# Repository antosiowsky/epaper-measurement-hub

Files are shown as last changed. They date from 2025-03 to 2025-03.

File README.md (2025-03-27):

# Epaper-EnvMonitor

A low-power environmental monitoring hub with an e-paper display, based on the M5StampS3 processor. It features a BME688 sensor for temperature, humidity, and air quality measurement, along with data storage and wireless communication.

## Features
- **Real-time environmental monitoring** (temperature, humidity, air quality)
- **E-paper display** for low-power data visualization
- **Data storage** for historical measurements
- **Wireless communication** (Wi-Fi/Bluetooth) for remote access
- **Energy-efficient design** suitable for battery-powered operation

## Hardware Components
- **M5StampS3** – ESP32-S3 based microcontroller
- **BME688** – Temperature, humidity, and gas sensor
- **E-paper display** – Low-power screen for data visualization
- **Memory module** – For data logging and storage

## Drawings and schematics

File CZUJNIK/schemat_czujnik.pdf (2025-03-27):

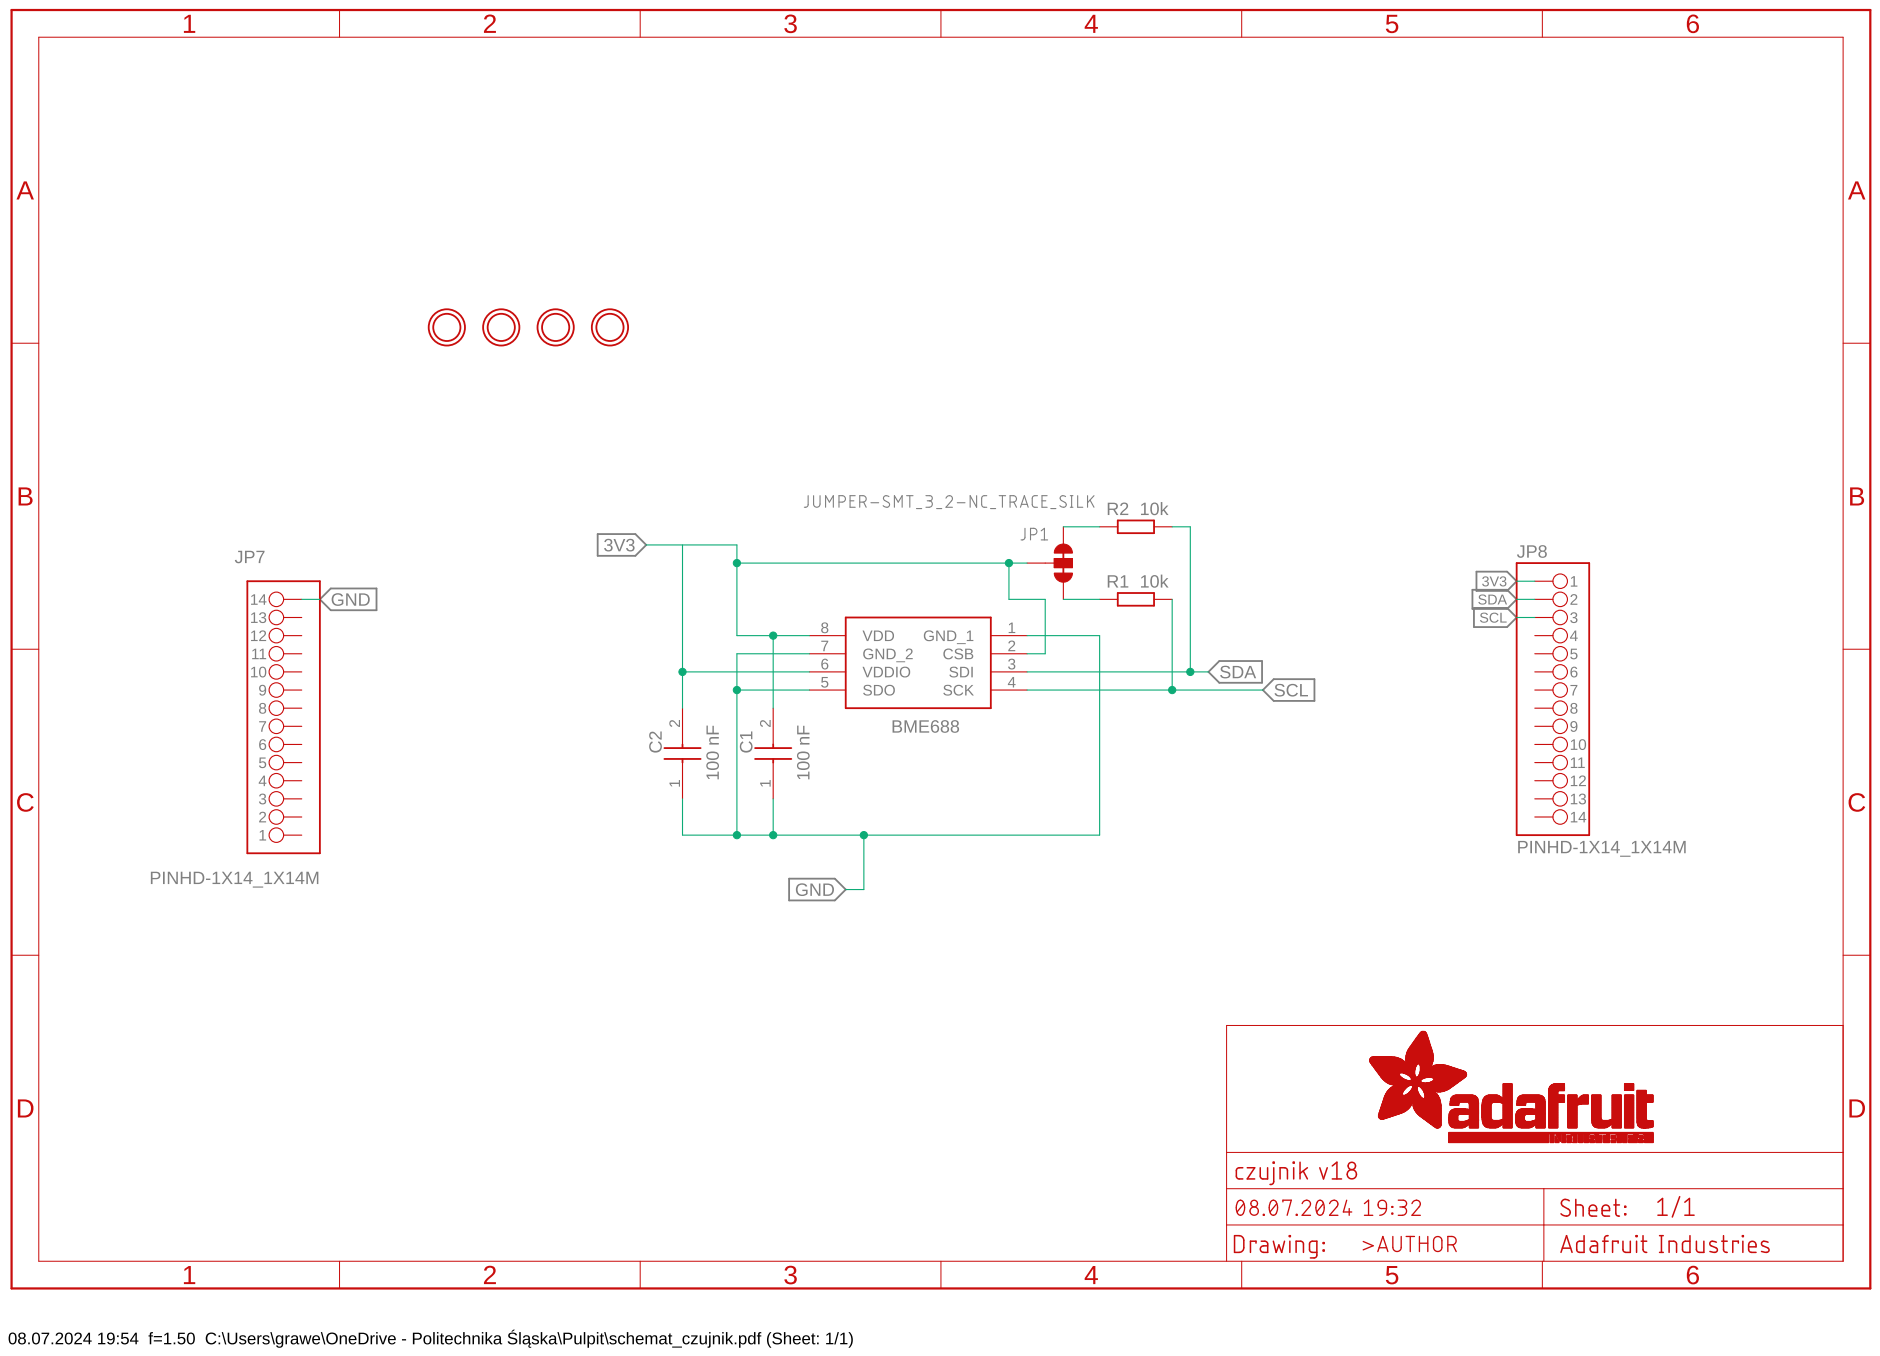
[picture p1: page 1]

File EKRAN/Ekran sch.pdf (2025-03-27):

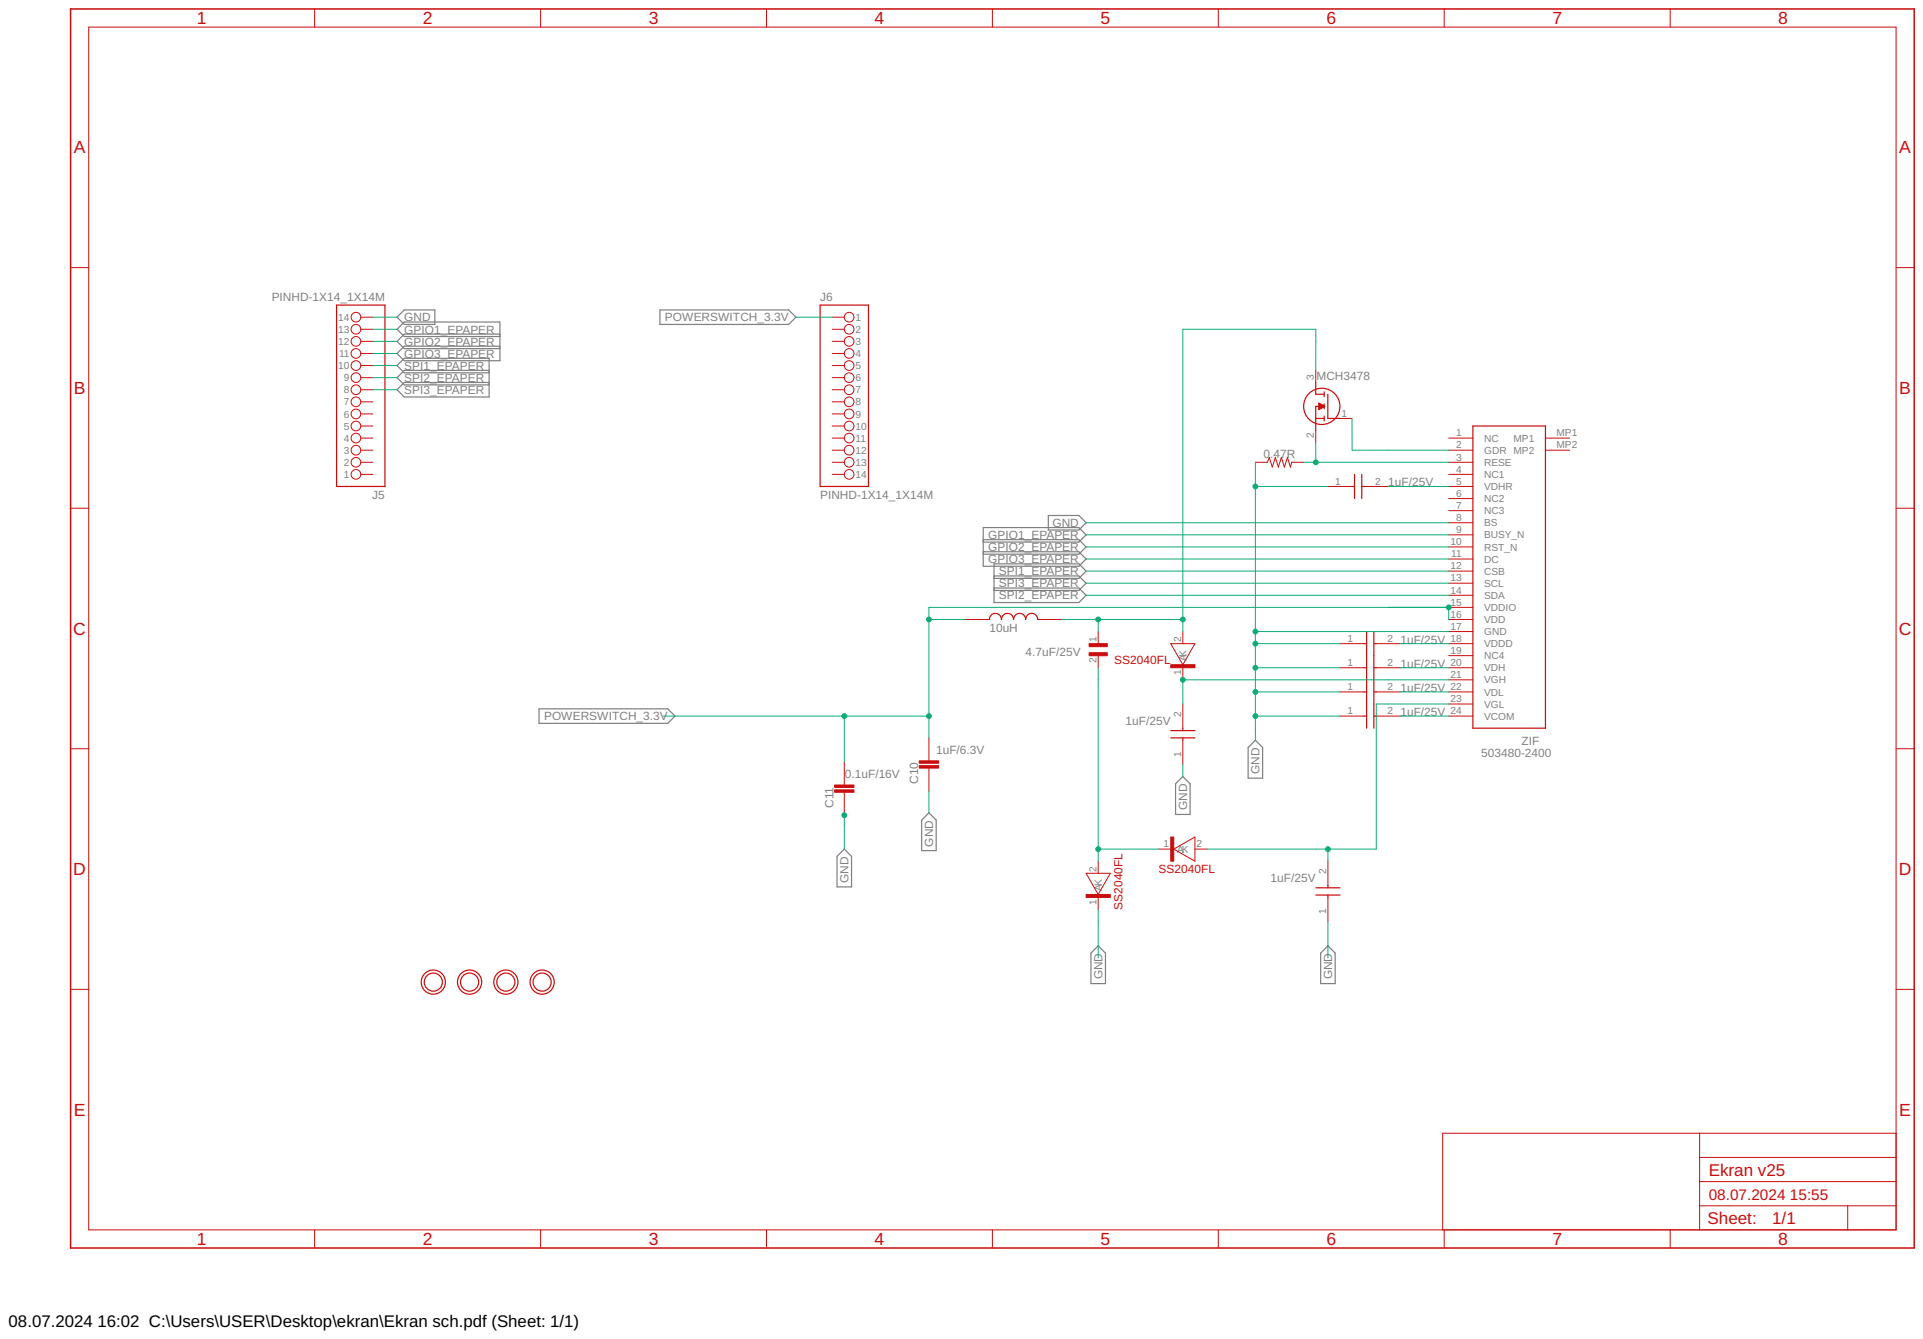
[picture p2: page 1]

08.07.2024 16:02 C:\Users\USER\Desktop\ekran\Ekran sch.pdf (Sheet: 1/1)

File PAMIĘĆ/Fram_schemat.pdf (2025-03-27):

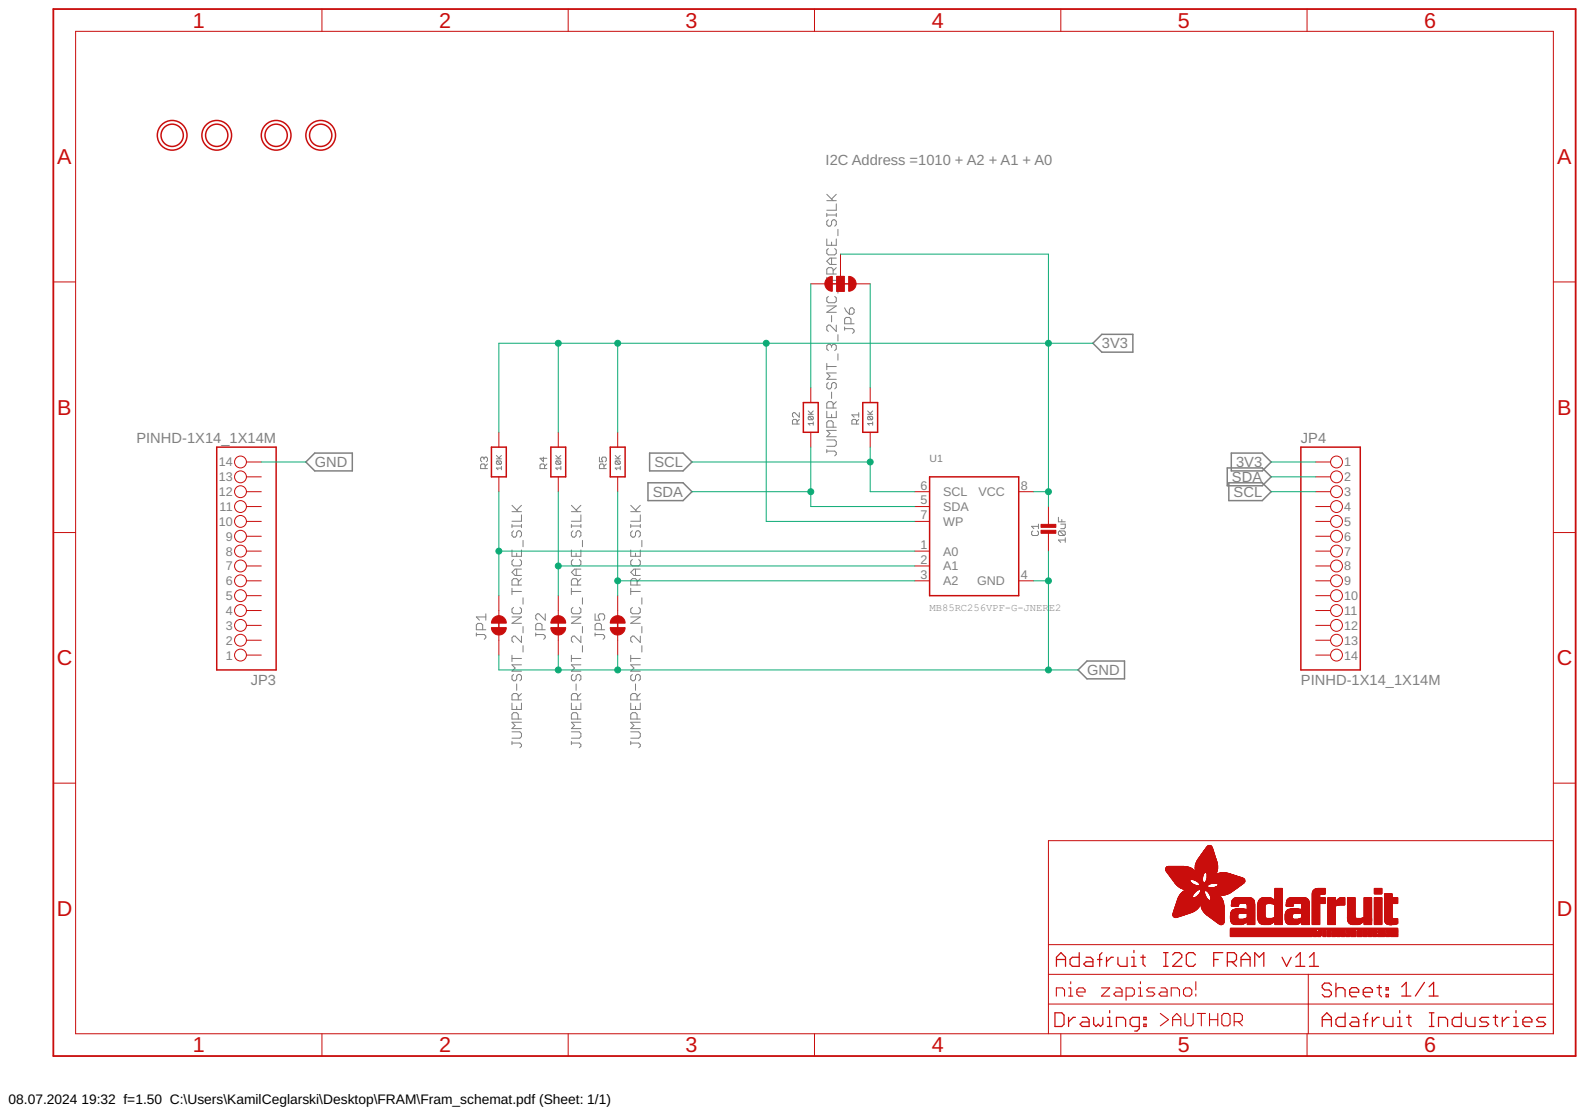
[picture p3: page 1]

08.07.2024 19:32 f=1.50 C:\Users\KamilCeglarski\Desktop\FRAM\Fram_schemat.pdf (Sheet: 1/1)

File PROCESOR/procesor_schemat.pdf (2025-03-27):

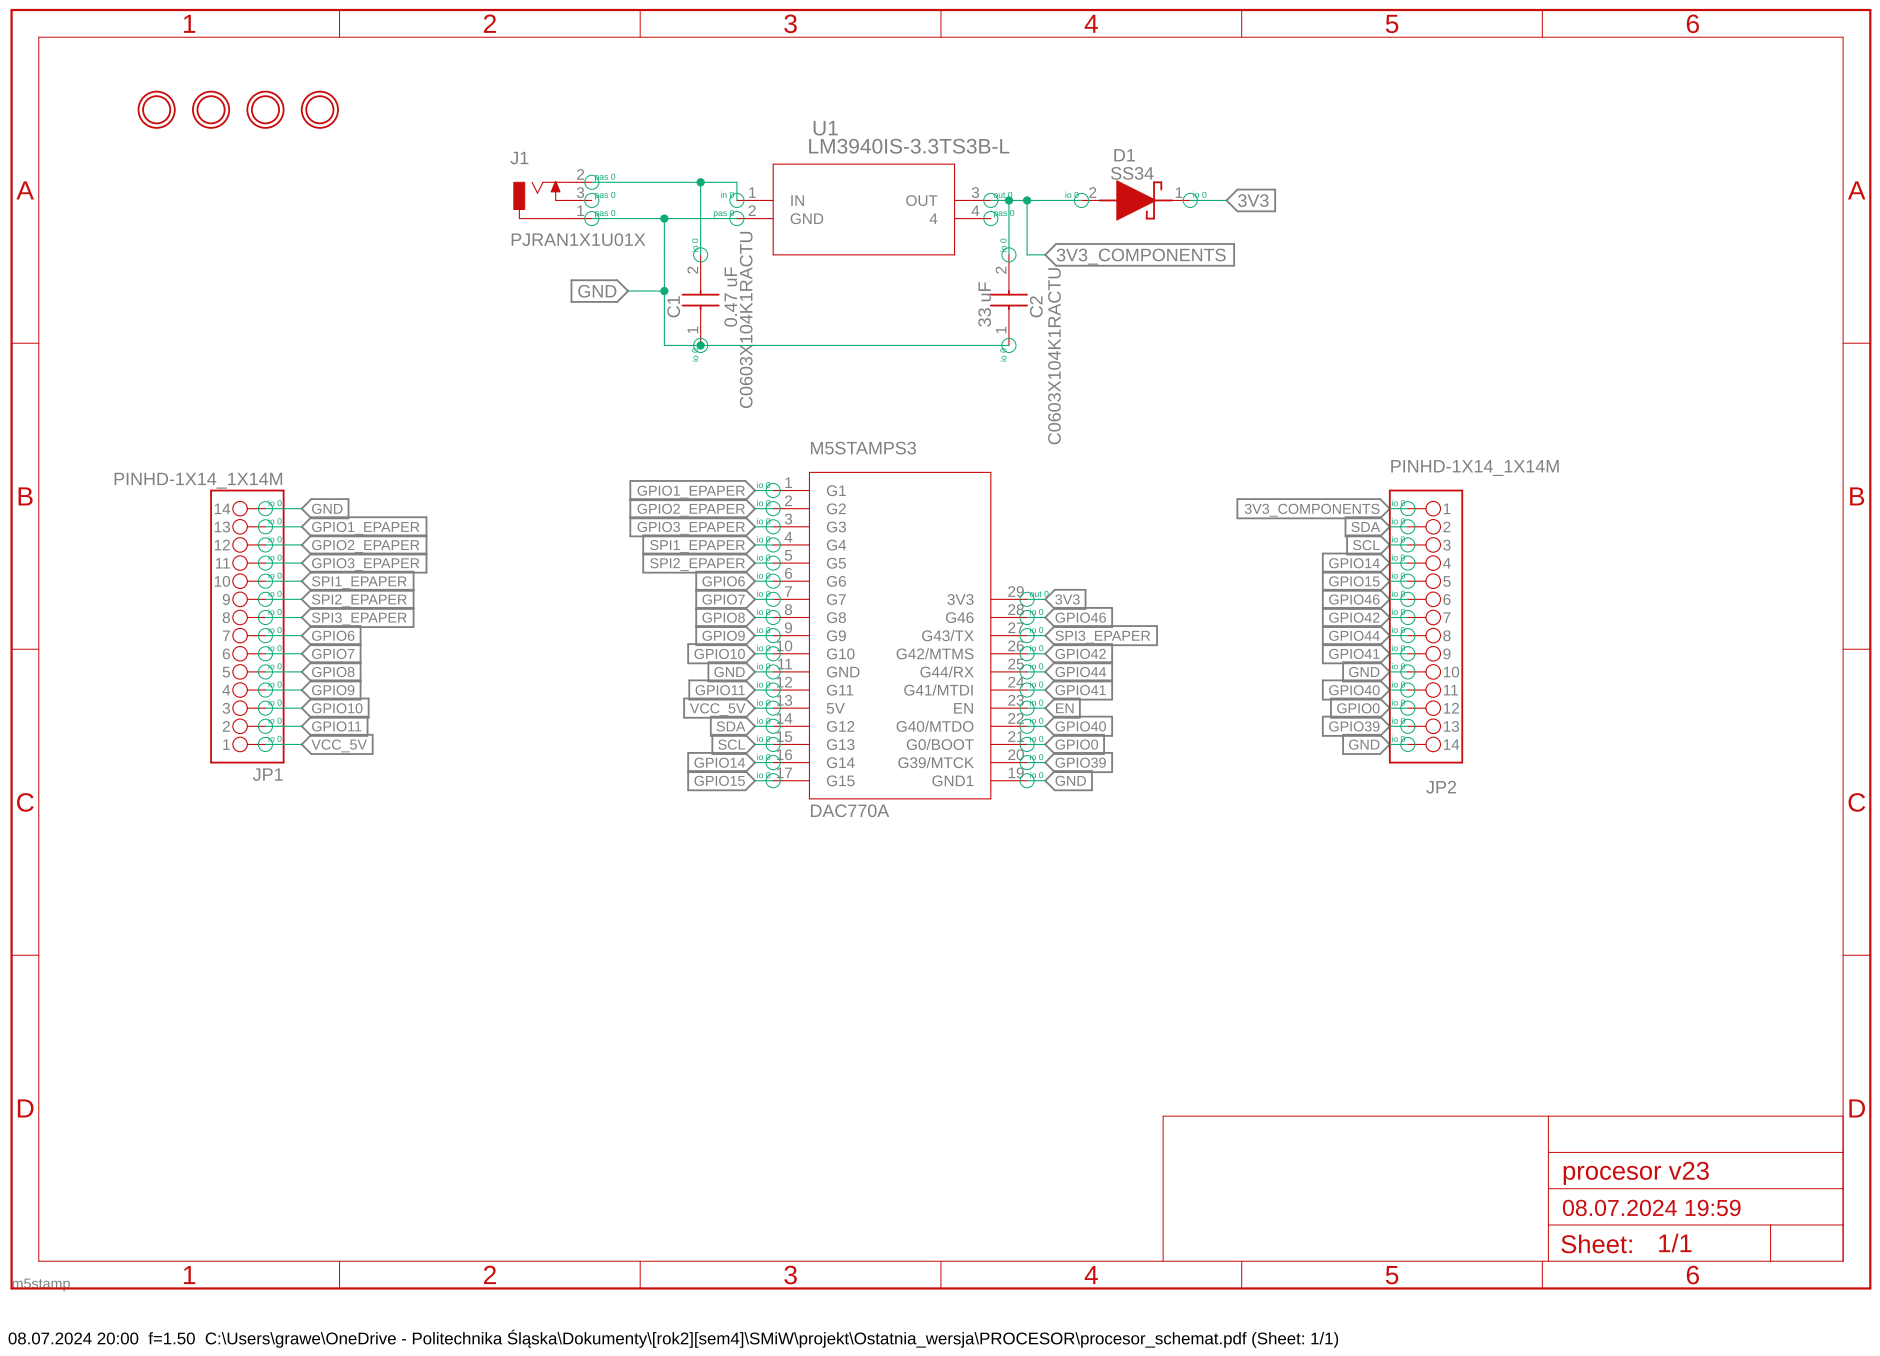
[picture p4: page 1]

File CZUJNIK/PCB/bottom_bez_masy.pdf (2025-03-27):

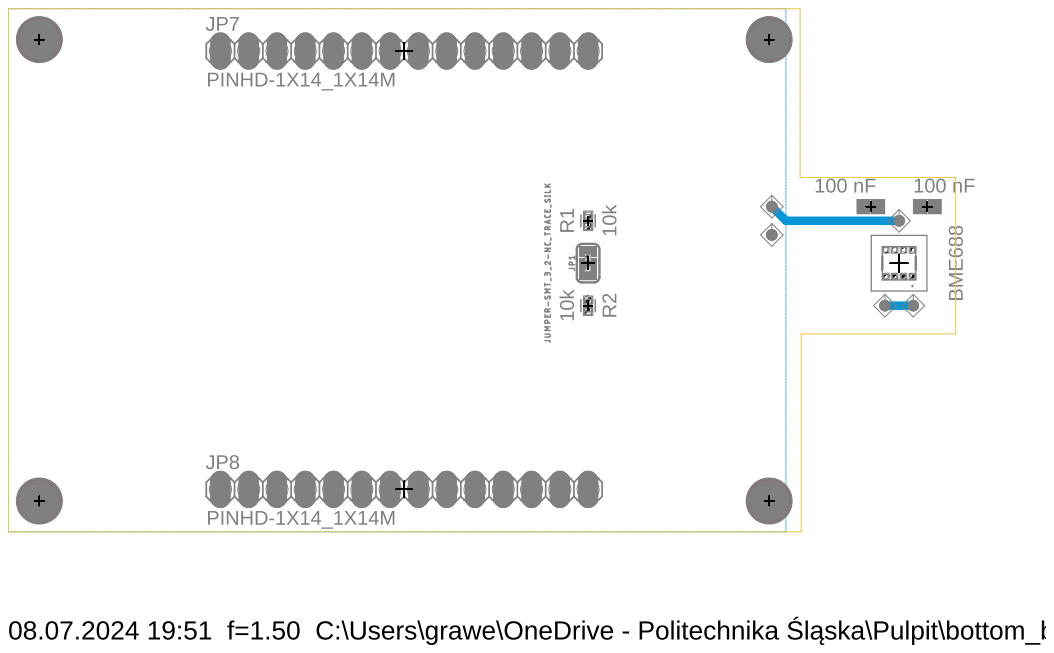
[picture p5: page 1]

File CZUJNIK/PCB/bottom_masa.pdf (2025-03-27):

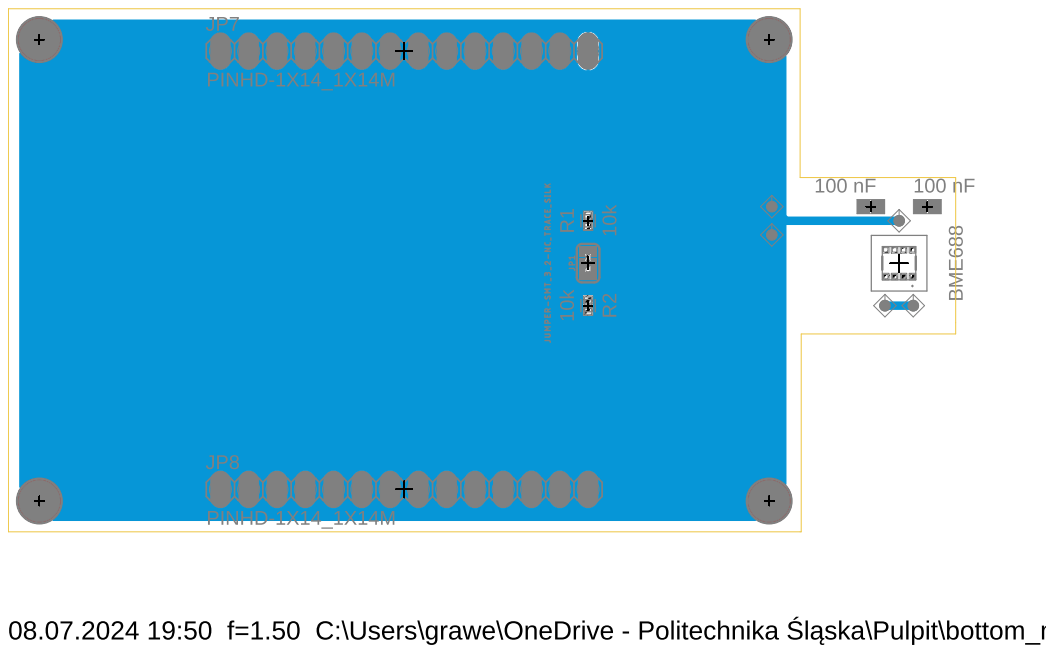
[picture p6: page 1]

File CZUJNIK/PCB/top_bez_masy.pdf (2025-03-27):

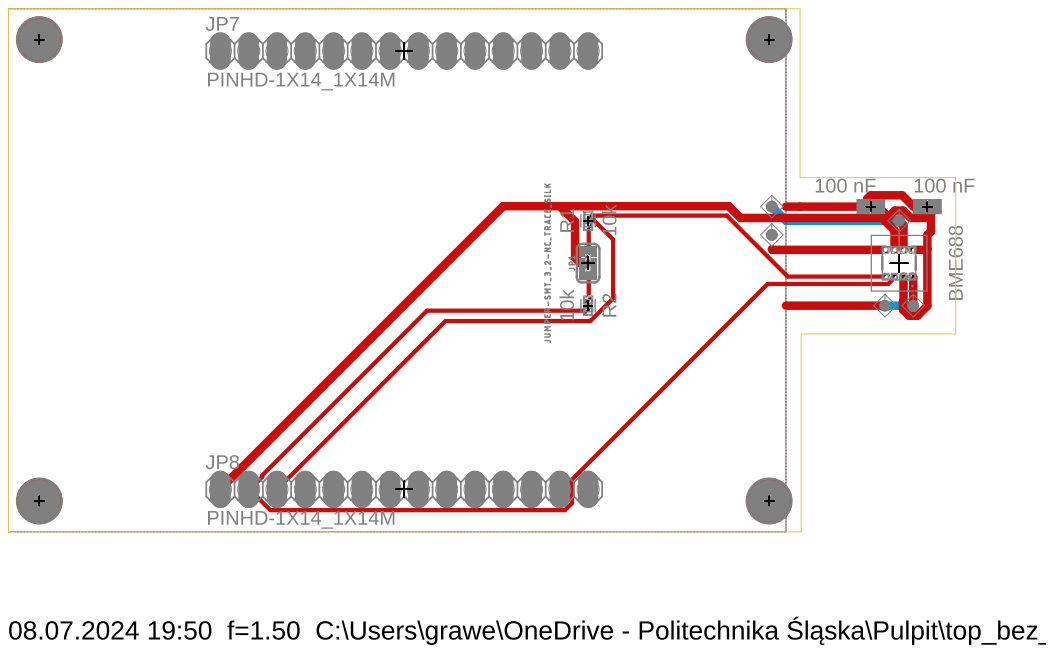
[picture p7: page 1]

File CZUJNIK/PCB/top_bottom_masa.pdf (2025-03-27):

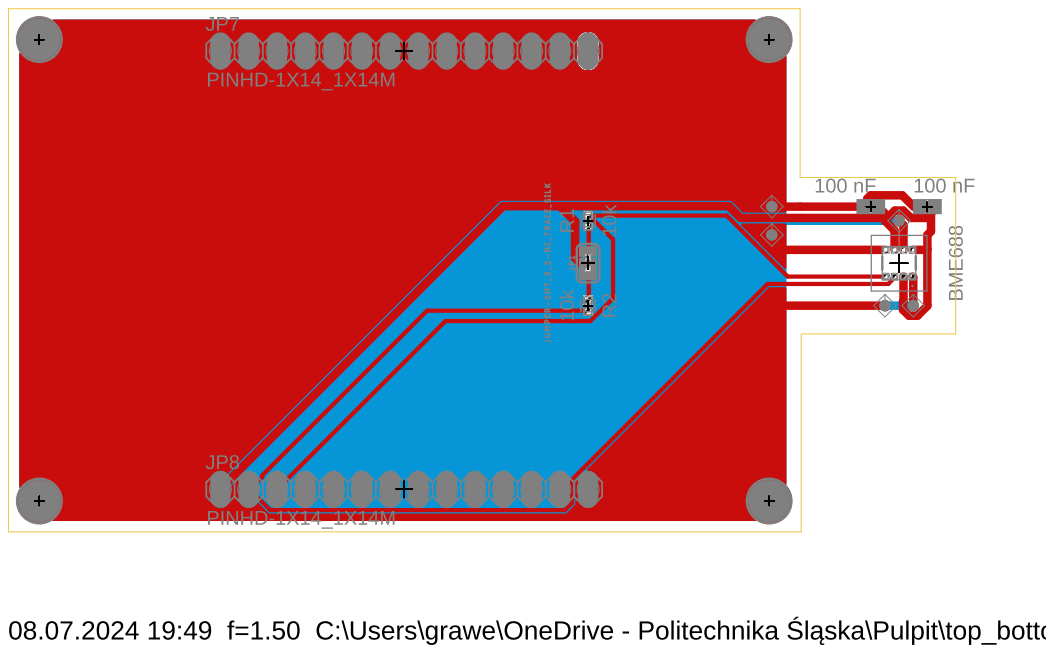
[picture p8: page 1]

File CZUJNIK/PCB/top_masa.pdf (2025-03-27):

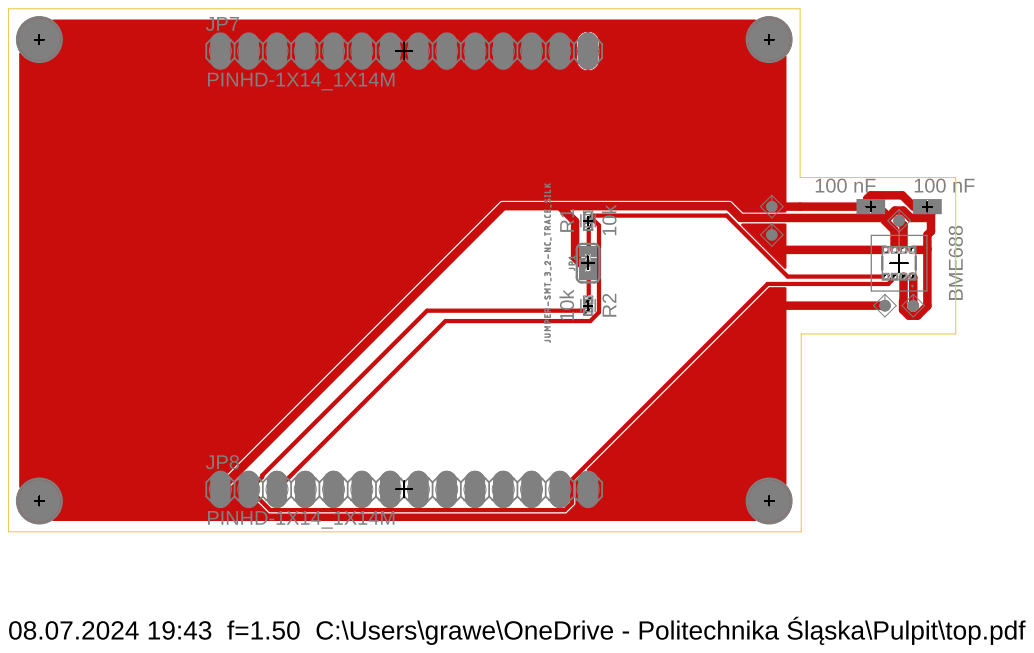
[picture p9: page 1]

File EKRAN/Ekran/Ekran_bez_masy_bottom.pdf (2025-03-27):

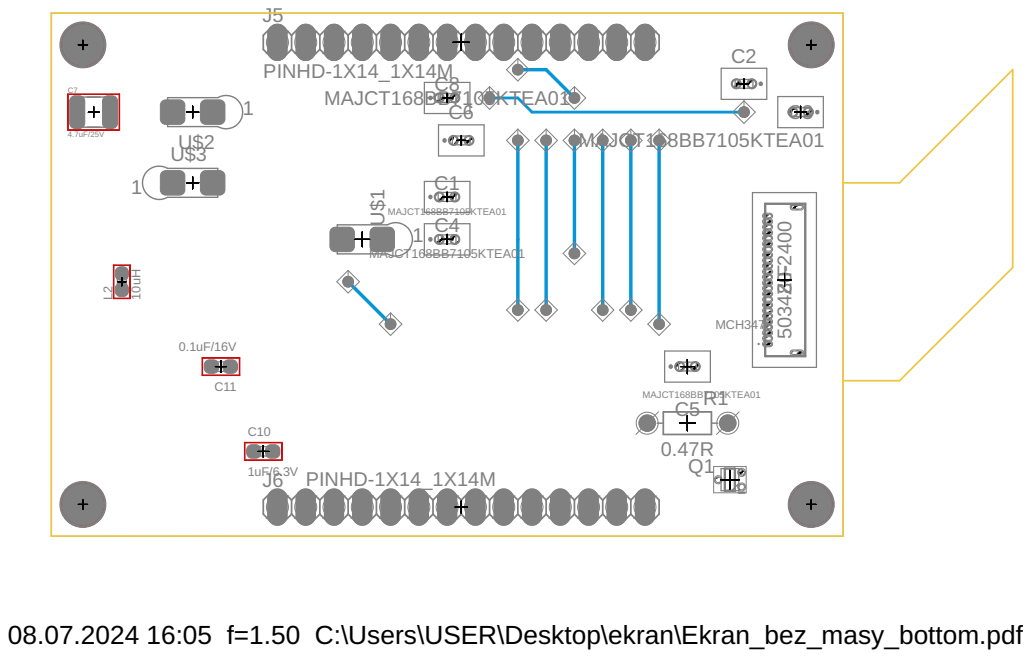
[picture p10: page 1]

08.07.2024 16:05 f=1.50 C:\Users\USER\Desktop\ekran\Ekran_bez_masy_bottom.pdf

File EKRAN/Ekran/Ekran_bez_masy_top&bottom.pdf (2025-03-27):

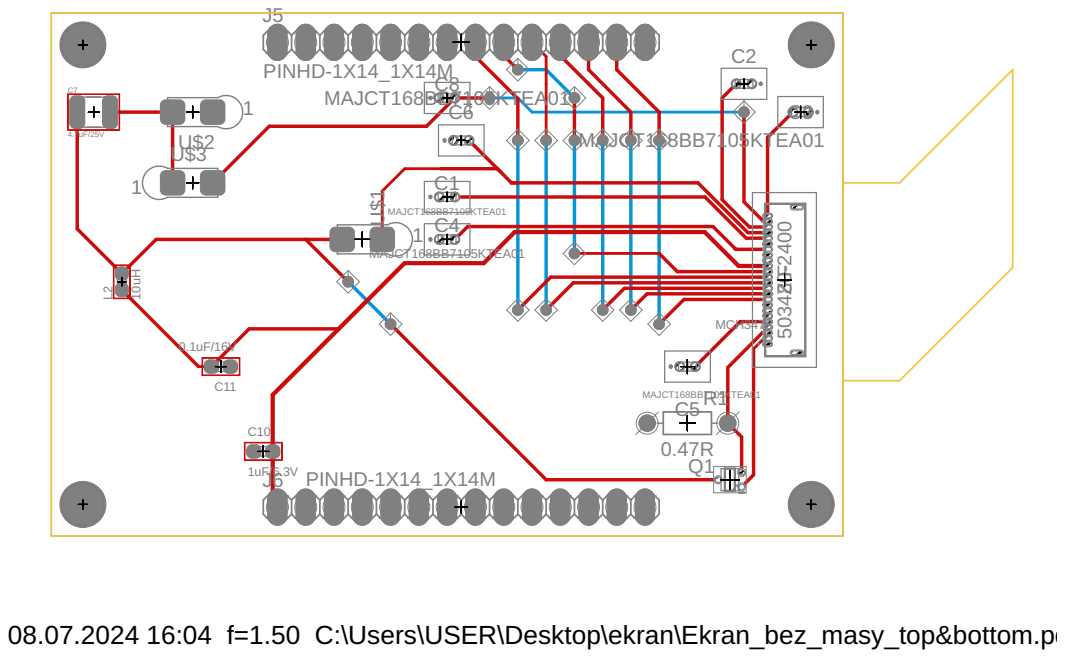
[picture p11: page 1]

08.07.2024 16:04 f=1.50 C:\Users\USER\Desktop\ekran\Ekran_bez_masy_top&bottom.pdf

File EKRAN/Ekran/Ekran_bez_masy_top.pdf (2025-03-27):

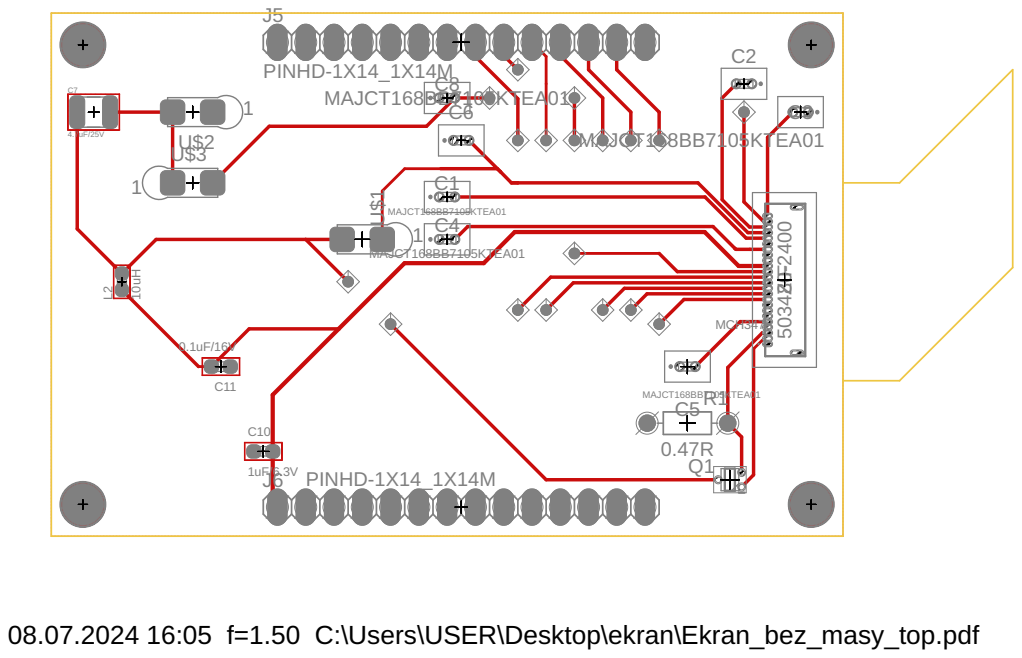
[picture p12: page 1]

08.07.2024 16:05 f=1.50 C:\Users\USER\Desktop\ekran\Ekran_bez_masy_top.pdf

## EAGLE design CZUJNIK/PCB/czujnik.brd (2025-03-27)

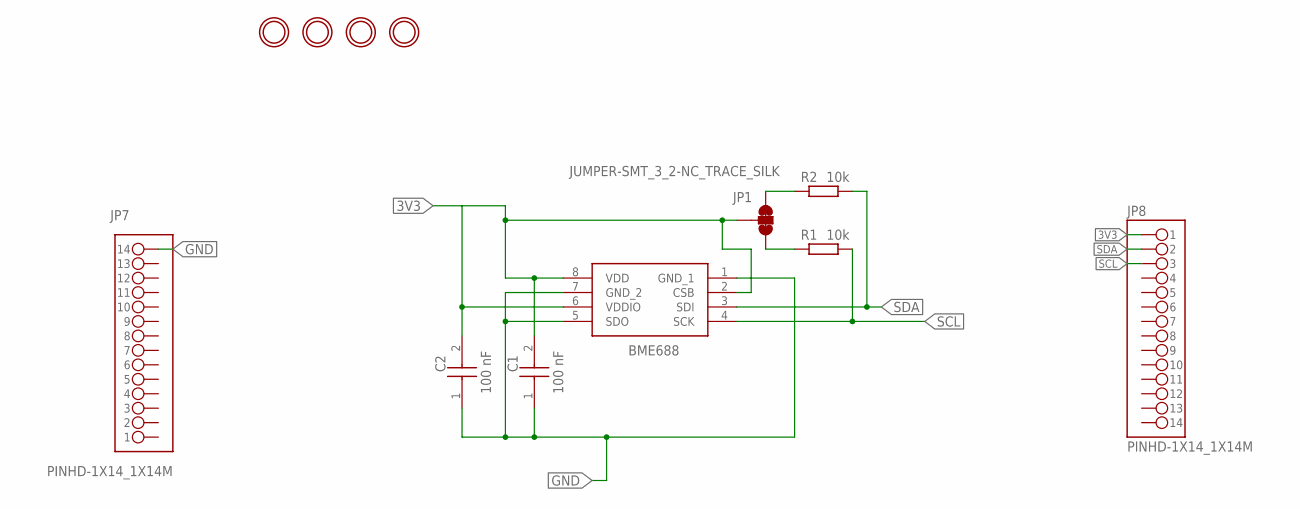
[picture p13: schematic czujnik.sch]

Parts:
BME688: BME688
C1, C2: C0603X104K1RACTU; CAPC1608X100N
JP1: JUMPER-SMT_3_2-NC_TRACE_SILK; SMT-JUMPER_3_2-NC_TRACE_SILK
JP7, JP8: PINHD-1X14_1X14M; 1X14
R1, R2: 10k; RESC1005X40
U$2, U$3, U$4, U$6: MOUNTINGHOLE2.5; MOUNTINGHOLE_2.5_PLATED

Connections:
3V3: BME688.2 (CSB), BME688.6 (VDDIO), BME688.8 (VDD), C1.2, C2.2, JP1.2, JP8.1
GND: BME688.1 (GND_1), BME688.5 (SDO), BME688.7 (GND_2), C1.1, C2.1, JP7.14
unnamed: JP1.1, R2.1
unnamed: JP1.3, R1.1
SCL: BME688.4 (SCK), JP8.3, R1.2
SDA: BME688.3 (SDI), JP8.2, R2.2

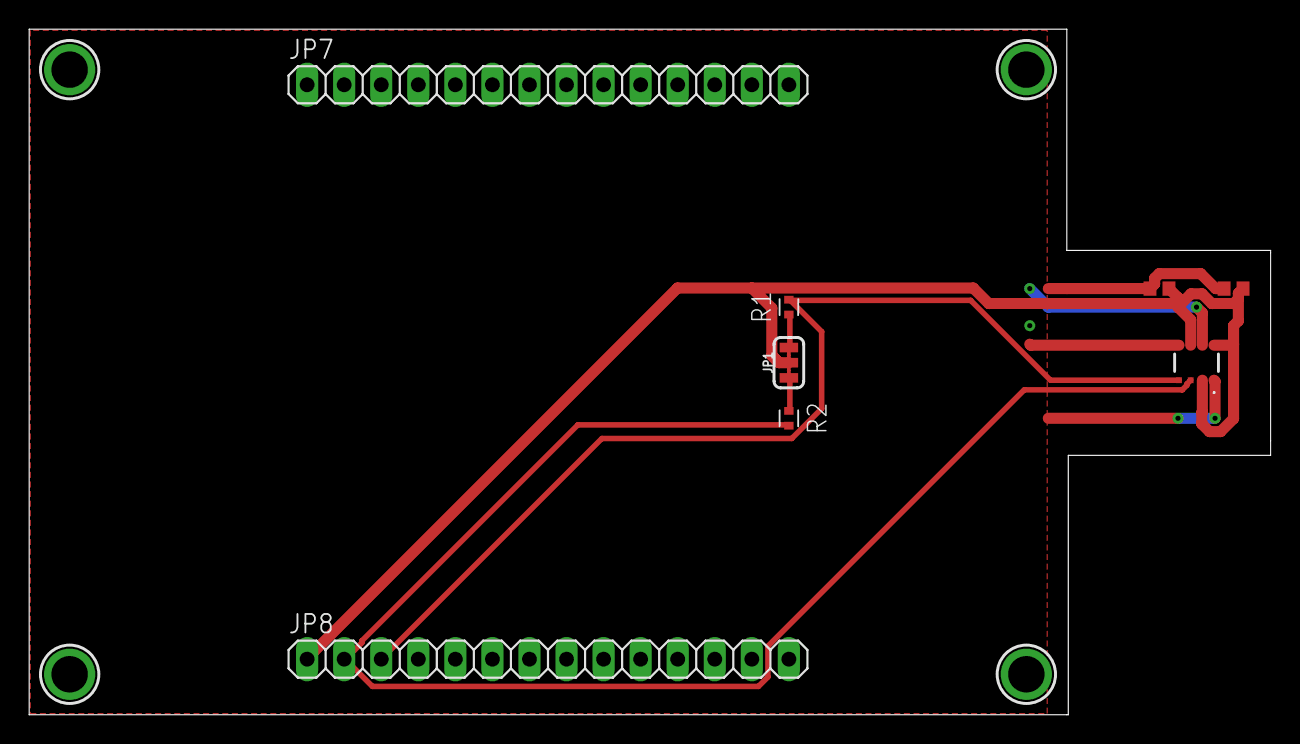
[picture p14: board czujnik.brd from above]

Board: 2 copper layers, 85.1 x 47.0 mm, 12 parts (0 on the bottom side), 6 nets.

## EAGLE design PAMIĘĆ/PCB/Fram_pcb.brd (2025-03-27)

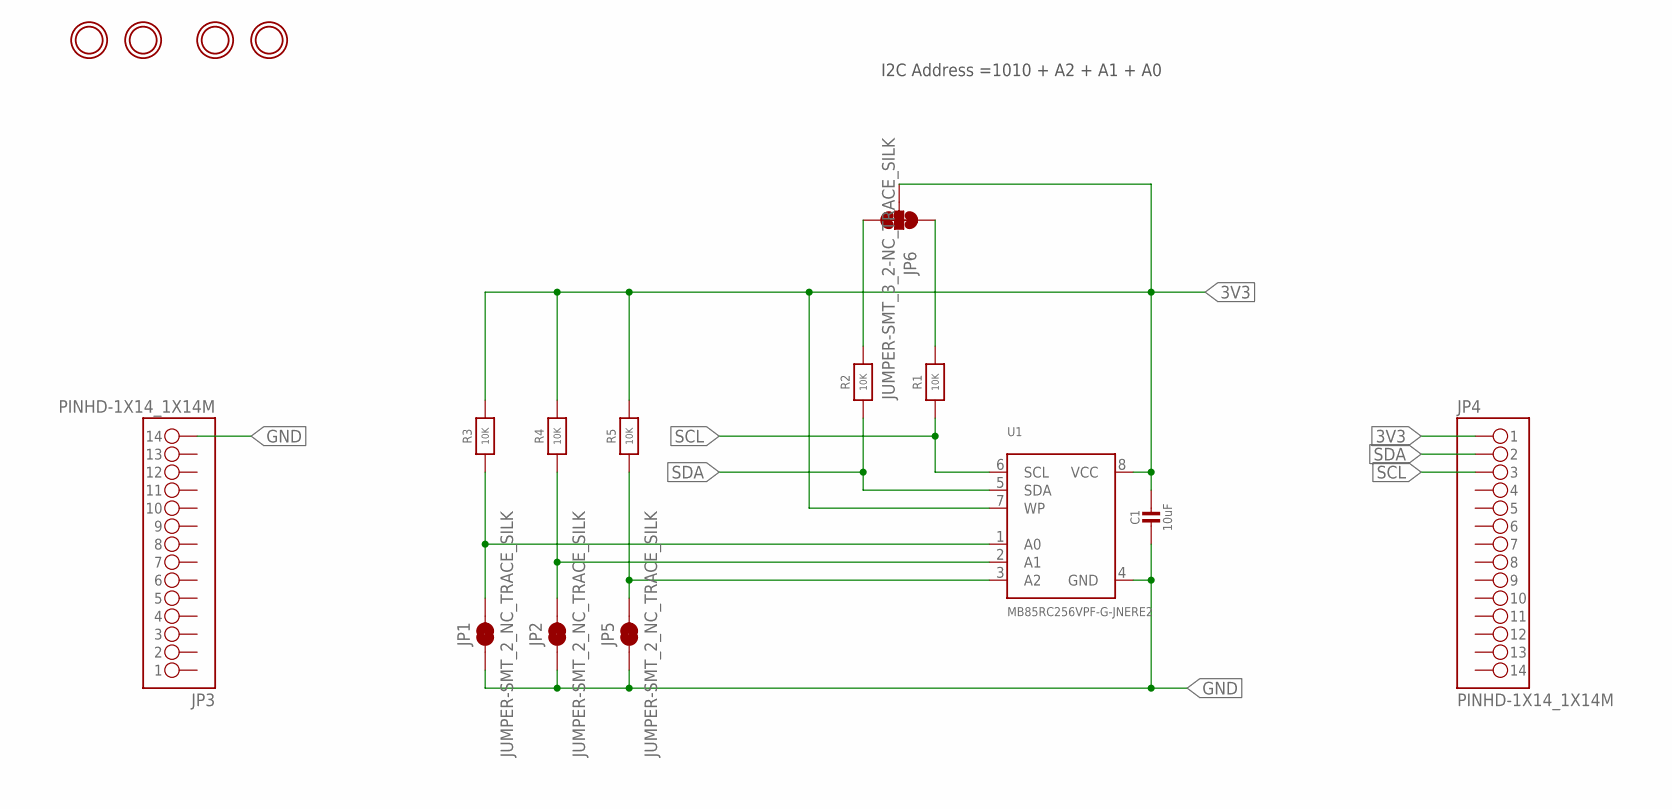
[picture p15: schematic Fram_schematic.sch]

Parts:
C1: 10uF; _0805MP
JP1, JP2, JP5: JUMPER-SMT_2_NC_TRACE_SILK; SMT-JUMPER_2_NC_TRACE_SILK
JP3, JP4: PINHD-1X14_1X14M; 1X14
JP6: JUMPER-SMT_3_2-NC_TRACE_SILK; SMT-JUMPER_3_2-NC_TRACE_SILK
R1, R2, R3, R4, R5: 10K; _0805MP
U1: MB85RC256VPF-G-JNERE2; SOIC8_208MIL
U$2, U$3, U$5, U$6: MOUNTINGHOLE2.5; MOUNTINGHOLE_2.5_PLATED

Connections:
3V3: C1.1, JP4.1, JP6.2, R3.2, R4.2, R5.2, U1.7 (WP), U1.8 (VCC)
GND: C1.2, JP1.1, JP2.1, JP3.14, JP5.1, U1.4 (GND)
SCL: JP4.3, JP6.1, R1.1, R1.2, U1.6 (SCL)
SDA: JP4.2, JP6.3, R2.1, R2.2, U1.5 (SDA)
SDA1: JP1.2, R3.1, U1.1 (A0)
SDA2: JP2.2, R4.1, U1.2 (A1)
SDA3: JP5.2, R5.1, U1.3 (A2)

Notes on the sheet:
I2C Address =1010 + A2 + A1 + A0

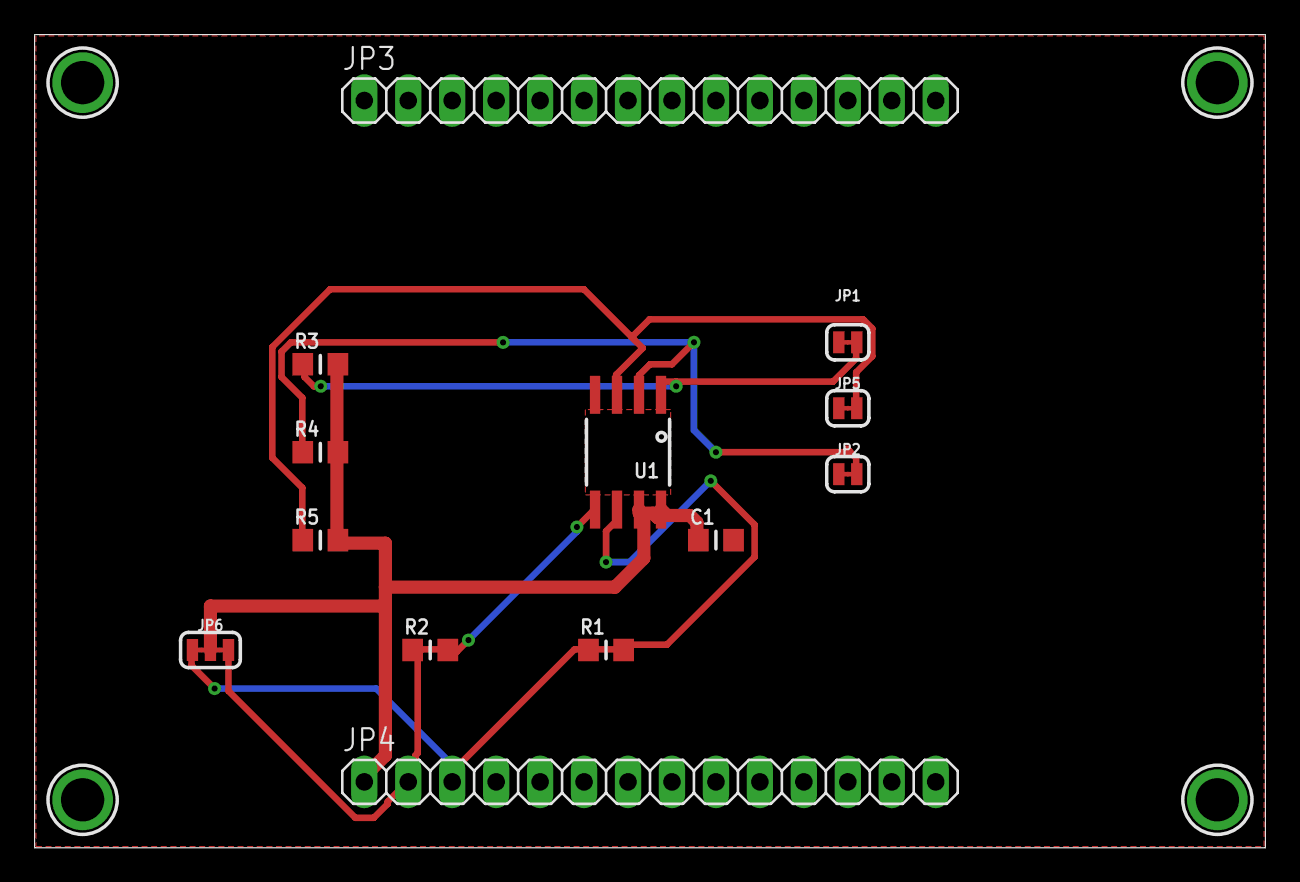
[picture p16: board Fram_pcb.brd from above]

Board: 2 copper layers, 71.1 x 47.0 mm, 17 parts (0 on the bottom side), 7 nets.

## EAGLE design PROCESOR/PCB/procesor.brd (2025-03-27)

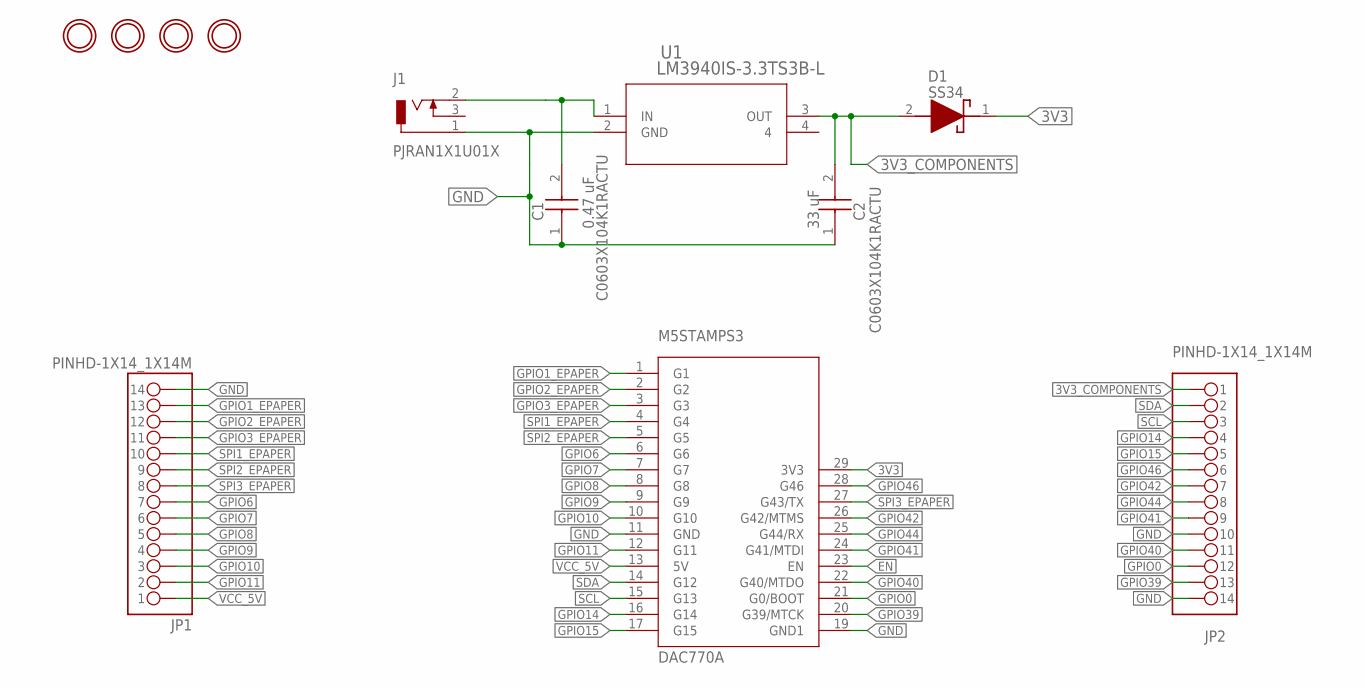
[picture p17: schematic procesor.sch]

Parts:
C1, C2: C0603X104K1RACTU; CAPC1608X100N
D1: SS34; DIOM8059X256N
J1: PJRAN1X1U01X
JP1, JP2: PINHD-1X14_1X14M; 1X14
M5STAMPS3: DAC770A; QFN127P2400X1800X470-36N
U1: LM3940IS-3.3TS3B-L; TS3B-L
U$1, U$3, U$5, U$6: MOUNTINGHOLE2.5; MOUNTINGHOLE_2.5_PLATED

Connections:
3V3: D1.1 (K), M5STAMPS3.29 (3V3)
3V3_COMPONENTS: C2.2, D1.2 (A), JP2.1, U1.3 (OUT)
EN: M5STAMPS3.23 (EN)
GND: C1.1, C2.1, J1.1, JP1.14, JP2.10, JP2.14, M5STAMPS3.11 (GND), M5STAMPS3.19 (GND1), U1.2 (GND)
GPIO0: JP2.12, M5STAMPS3.21 (G0/BOOT)
GPIO1_EPAPER: JP1.13, M5STAMPS3.1 (G1)
GPIO2_EPAPER: JP1.12, M5STAMPS3.2 (G2)
GPIO3_EPAPER: JP1.11, M5STAMPS3.3 (G3)
GPIO6: JP1.7, M5STAMPS3.6 (G6)
GPIO7: JP1.6, M5STAMPS3.7 (G7)
GPIO8: JP1.5, M5STAMPS3.8 (G8)
GPIO9: JP1.4, M5STAMPS3.9 (G9)
GPIO10: JP1.3, M5STAMPS3.10 (G10)
GPIO11: JP1.2, M5STAMPS3.12 (G11)
GPIO14: JP2.4, M5STAMPS3.16 (G14)
GPIO15: JP2.5, M5STAMPS3.17 (G15)
GPIO39: JP2.13, M5STAMPS3.20 (G39/MTCK)
GPIO40: JP2.11, M5STAMPS3.22 (G40/MTDO)
GPIO41: JP2.9, M5STAMPS3.24 (G41/MTDI)
GPIO42: JP2.7, M5STAMPS3.26 (G42/MTMS)
GPIO44: JP2.8, M5STAMPS3.25 (G44/RX)
GPIO46: JP2.6, M5STAMPS3.28 (G46)
unnamed: C1.2, J1.2, U1.1 (IN)
SCL: JP2.3, M5STAMPS3.15 (G13)
SDA: JP2.2, M5STAMPS3.14 (G12)
SPI1_EPAPER: JP1.10, M5STAMPS3.4 (G4)
SPI2_EPAPER: JP1.9, M5STAMPS3.5 (G5)
SPI3_EPAPER: JP1.8, M5STAMPS3.27 (G43/TX)
VCC_5V: JP1.1, M5STAMPS3.13 (5V)

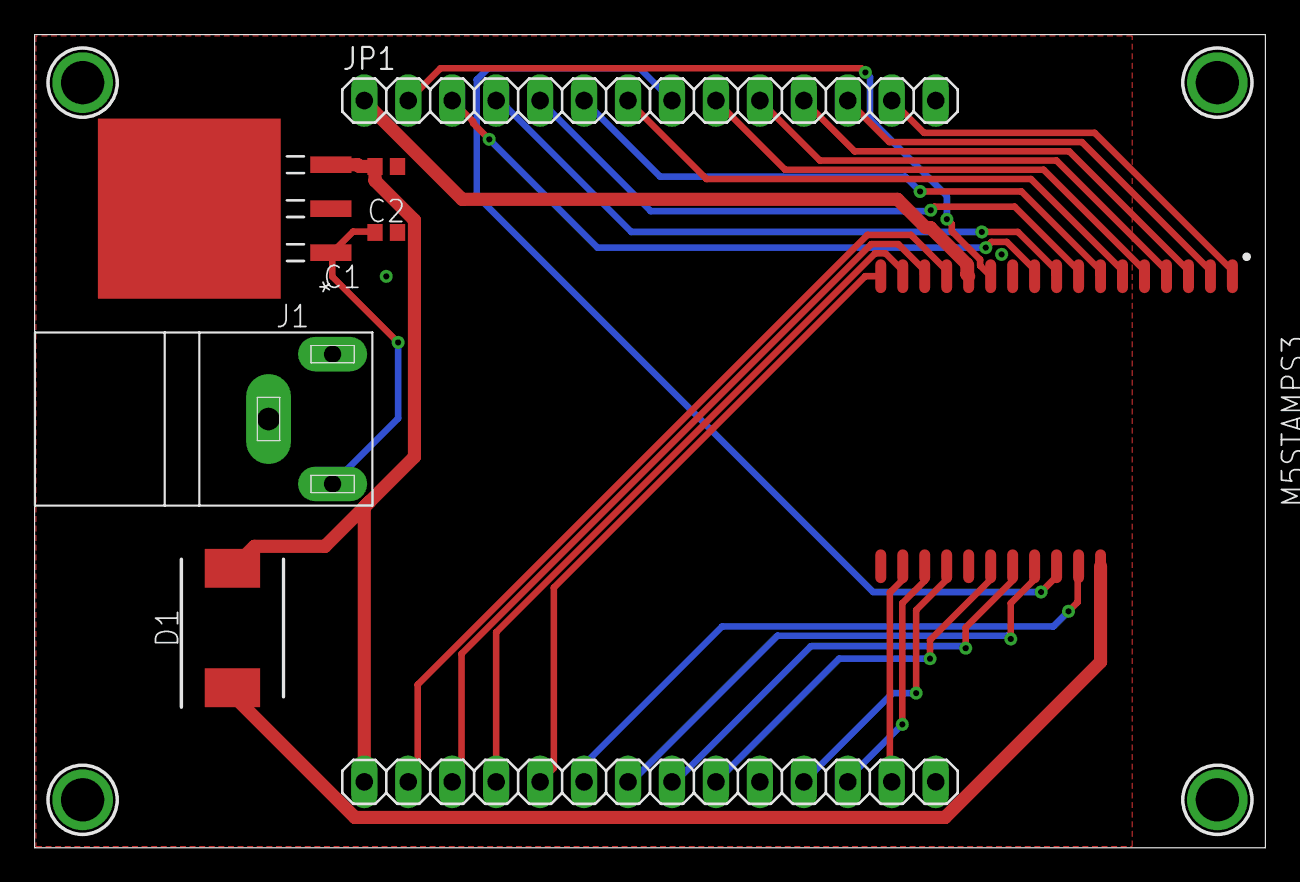
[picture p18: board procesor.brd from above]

Board: 2 copper layers, 71.1 x 47.0 mm, 12 parts (0 on the bottom side), 28 nets.

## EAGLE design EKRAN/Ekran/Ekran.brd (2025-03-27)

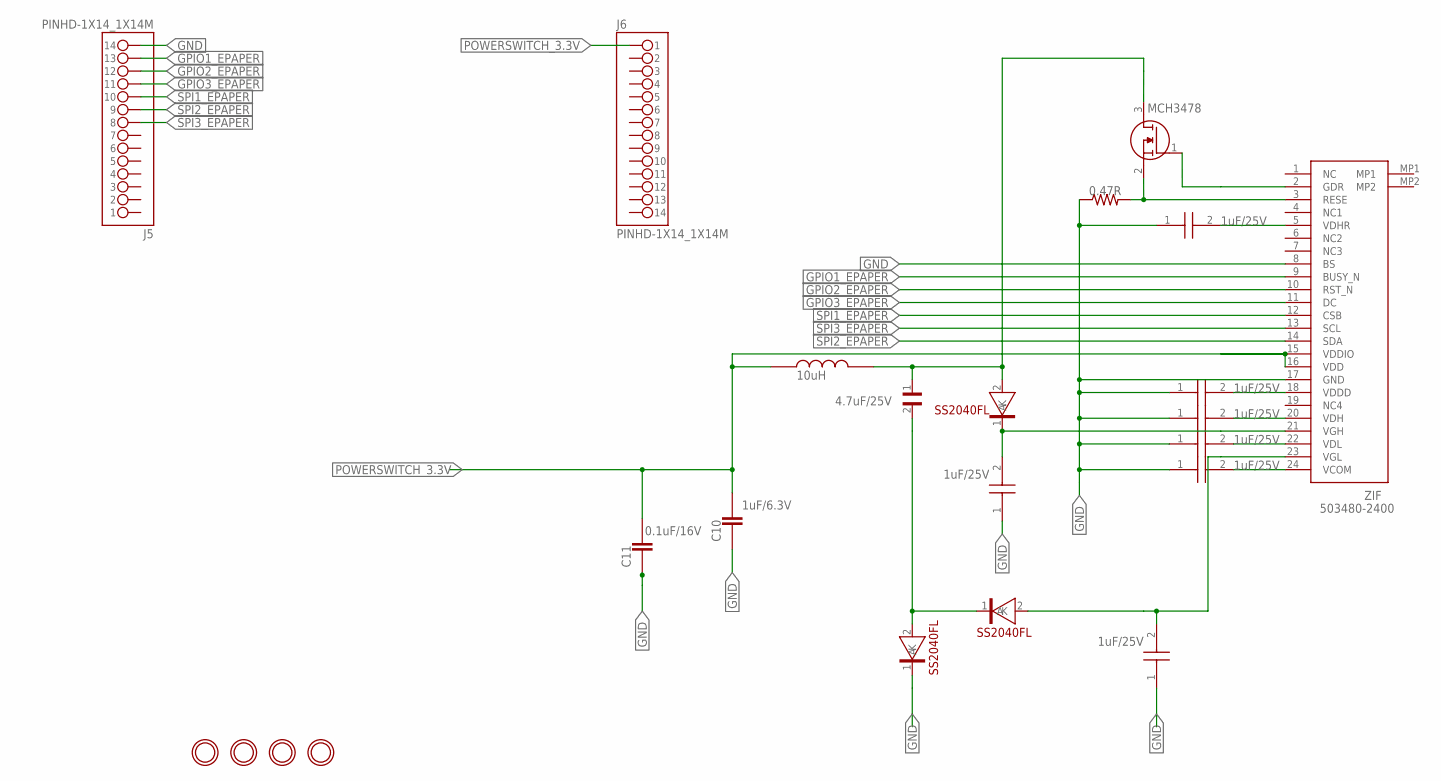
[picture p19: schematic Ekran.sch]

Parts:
C1, C2, C3, C4, C5, C6, C8: MAJCT168BB7105KTEA01; MAJX16
C7: 4.7uF/25V; CAPC3225X280N
C10: 1uF/6.3V; CAPC1608X90
C11: 0.1uF/16V; CAPC1608X90
J5, J6: PINHD-1X14_1X14M; 1X14
L2: 10uH; INDC1608X95N
Q1: MCH3478; SOTFL65P210X90-3N
R1: 0.47R; RESAD724W46L381D178B
U$1, U$2, U$3: SS2040FL; SOD-123FL
U$4, U$5, U$6, U$7: MOUNTINGHOLE2.5; MOUNTINGHOLE_2.5_PLATED
ZIF: 503480-2400; 5034802400

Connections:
GND: C1.1, C2.1, C3.1, C4.1, C5.1, C6.1, C8.1, C10.1, C11.1, J5.14, R1.1, U$2.1 (K), ZIF.8 (BS), ZIF.17 (GND)
GPIO1_EPAPER: J5.13, ZIF.9 (BUSY_N)
GPIO2_EPAPER: J5.12, ZIF.10 (RST_N)
GPIO3_EPAPER: J5.11, ZIF.11 (DC)
unnamed: Q1.1 (G), ZIF.2 (GDR)
unnamed: C5.2, ZIF.5 (VDHR)
unnamed: C4.2, ZIF.18 (VDDD)
unnamed: C7.2, U$2.2 (A), U$3.1 (K)
unnamed: C7.1, L2.2, Q1.3 (D), U$1.2 (A)
unnamed: C1.2, ZIF.20 (VDH)
unnamed: C6.2, U$1.1 (K), ZIF.21 (VGH)
unnamed: C2.2, ZIF.22 (VDL)
unnamed: C8.2, U$3.2 (A), ZIF.23 (VGL)
unnamed: C3.2, ZIF.24 (VCOM)
unnamed: Q1.2 (S), R1.2, ZIF.3 (RESE)
POWERSWITCH_3.3V: C10.2, C11.2, J6.1, L2.1, ZIF.15 (VDDIO), ZIF.16 (VDD)
SPI1_EPAPER: J5.10, ZIF.12 (CSB)
SPI2_EPAPER: J5.9, ZIF.14 (SDA)
SPI3_EPAPER: J5.8, ZIF.13 (SCL)

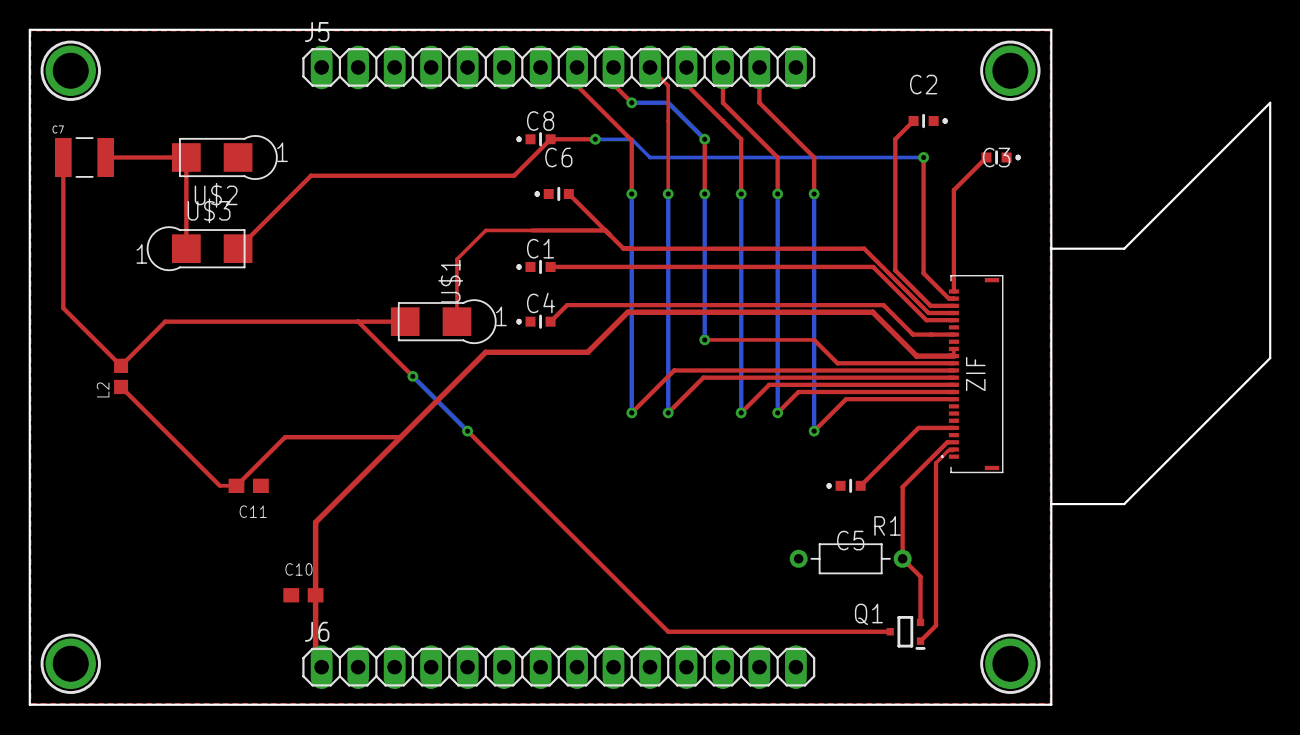
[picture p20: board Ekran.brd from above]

Board: 2 copper layers, 86.4 x 47.0 mm, 23 parts (0 on the bottom side), 19 nets.

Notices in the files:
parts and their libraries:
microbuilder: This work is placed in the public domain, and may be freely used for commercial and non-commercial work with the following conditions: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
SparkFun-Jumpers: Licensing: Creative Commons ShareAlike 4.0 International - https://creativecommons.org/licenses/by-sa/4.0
